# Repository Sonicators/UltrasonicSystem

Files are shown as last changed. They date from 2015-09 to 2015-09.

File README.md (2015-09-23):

A small ultrasonic system which can be used by hobbyists for:

* Mixing
* Cell disruption
* Levitation
* Cavitation experiments
* Ultrasonic chemistry
* ...and other tasks

The system consists of a transducer, a tuned aluminum horn, an ATX supply for power, an SMPS transformer from a second power supply, a PCB power driver, and mounting hardware.

Not counting the two ATX power supplies, a complete system can be made for around $60USD, more or less, depending on how good you are at scavenging.

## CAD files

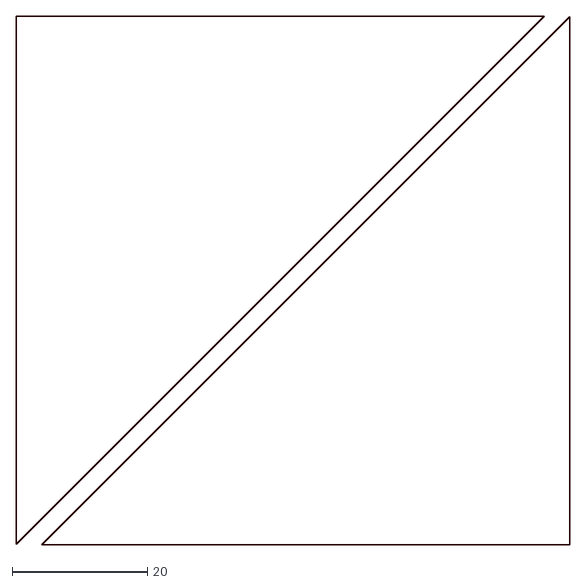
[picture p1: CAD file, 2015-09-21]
Hardware/45mm/CameraMount/BraceCorners.dxf
81.8 x 78.1

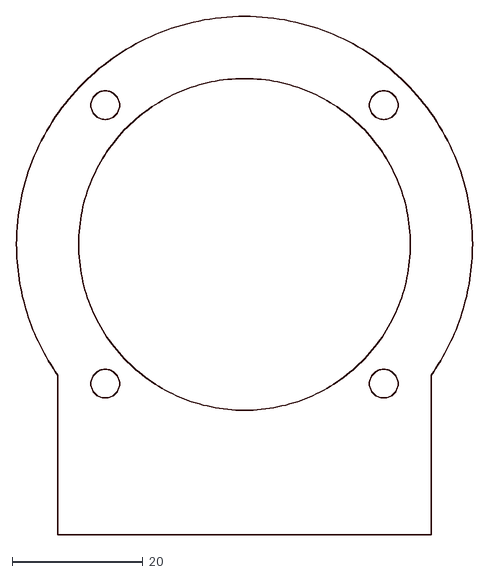
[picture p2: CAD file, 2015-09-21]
Hardware/45mm/Clamp/UpperClamp.dxf
69.8 x 79.4

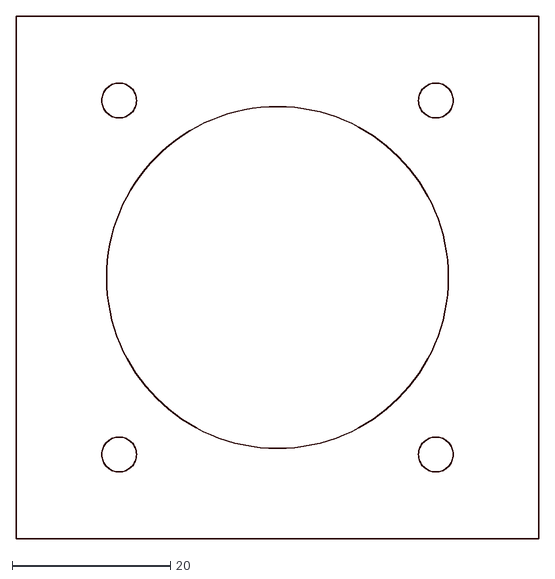
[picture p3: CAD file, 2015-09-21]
Hardware/45mm/DrillPressMount/Ring.dxf
66.0 x 66.0

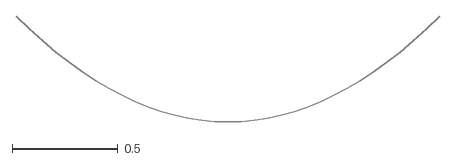
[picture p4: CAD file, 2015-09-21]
Hardware/45mm/ParabolicHorn/Anvil/Parabola Diameter 1.75 Depth .25.dxf
2.00 x 0.5

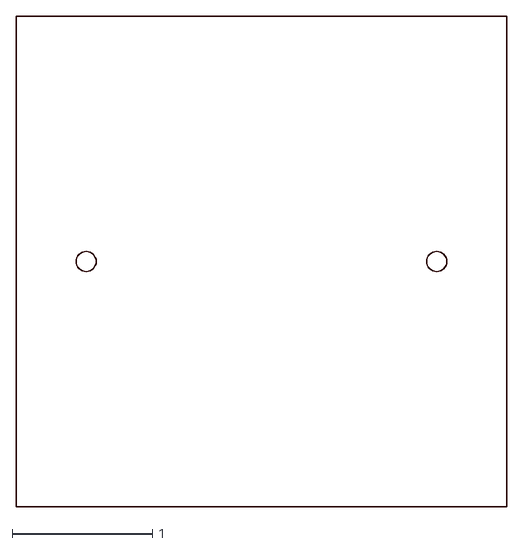
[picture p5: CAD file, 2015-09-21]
Hardware/45mm/ParabolicHorn/AnvilBase/AnvilBase.dxf
3.50 x 3.50

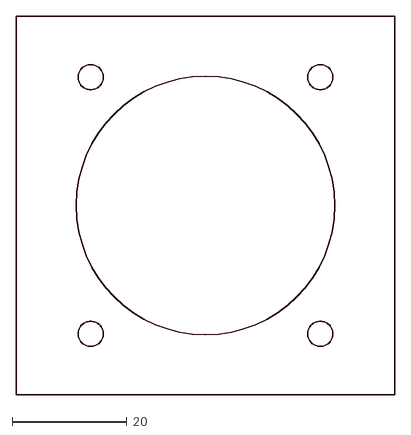
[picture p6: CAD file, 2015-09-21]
Hardware/45mm/ParabolicHorn/DrillPressMount/Ring.dxf
66.0 x 66.0

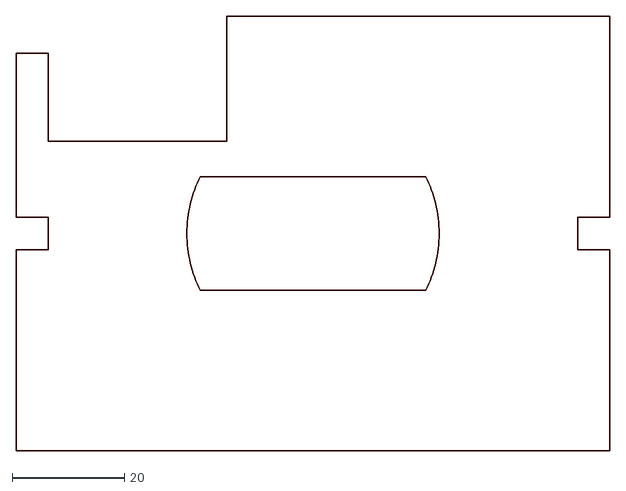
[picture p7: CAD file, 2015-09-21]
Hardware/45mm/ParabolicHorn/ReactionChamber/Top.dxf
105.6 x 77.3

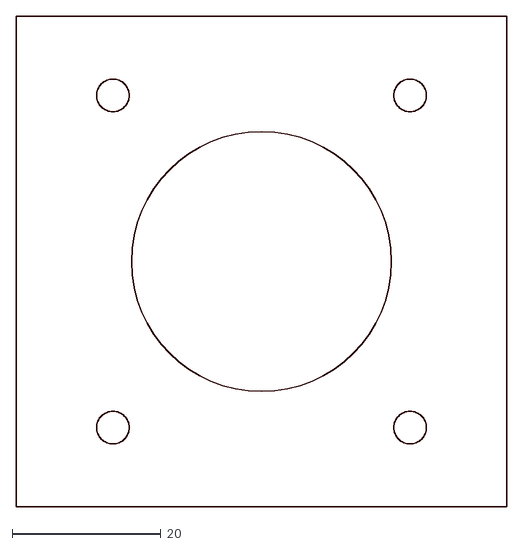
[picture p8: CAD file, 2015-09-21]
Hardware/45mm/StepHorn/DrillPressMount/LowerClamp.dxf
66.0 x 66.0

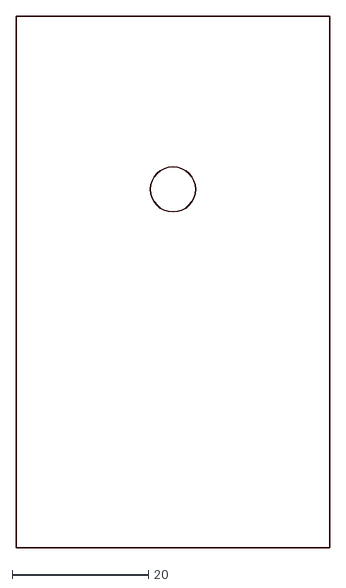
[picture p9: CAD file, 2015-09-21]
Hardware/67mm/CameraMount/CameraBase.dxf
46.0 x 78.0

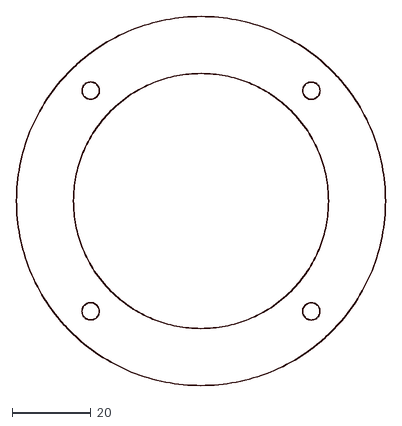
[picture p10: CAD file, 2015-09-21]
Hardware/67mm/Clamp/Ring.dxf
93.6 x 93.6

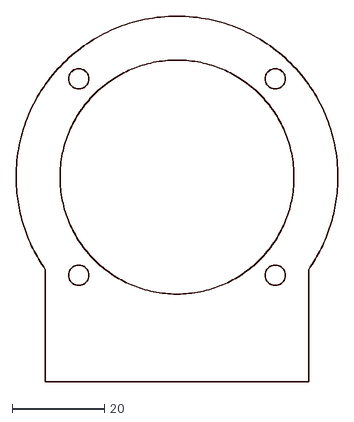
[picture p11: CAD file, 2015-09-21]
Hardware/45mm/CameraMount/UpperClamp.dxf
69.8 x 79.4

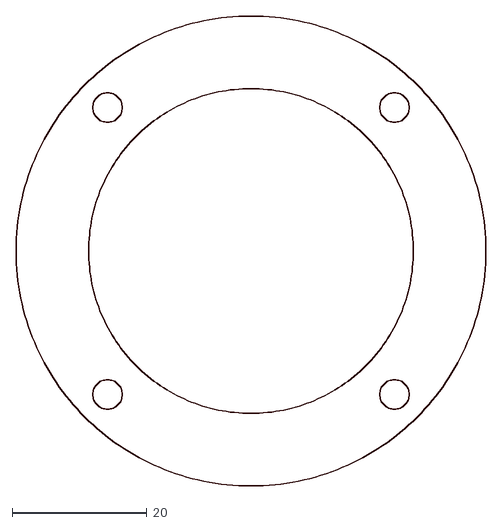
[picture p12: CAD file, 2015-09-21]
Hardware/45mm/Clamp/Ring.dxf
69.8 x 69.8

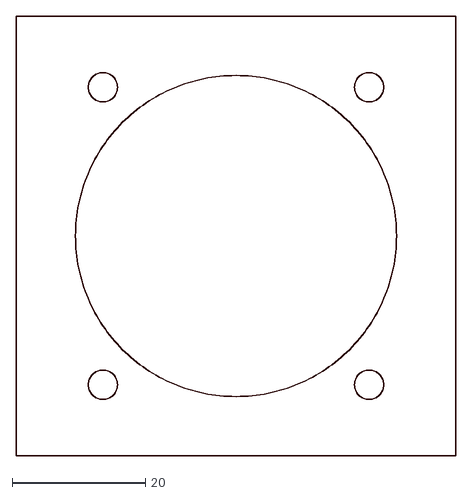
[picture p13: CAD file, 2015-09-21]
Hardware/45mm/DrillPressMount/LowerClamp.dxf
66.0 x 66.0

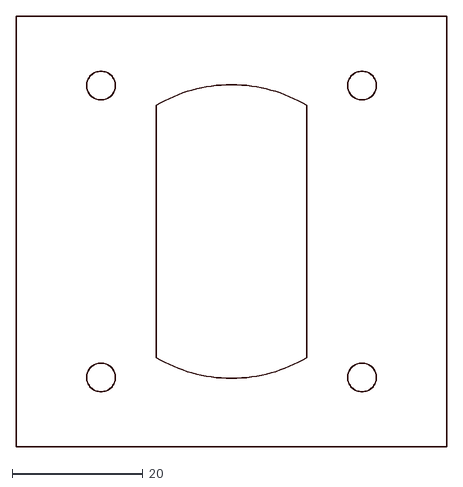
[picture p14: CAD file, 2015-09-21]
Hardware/45mm/ParabolicHorn/DrillPressMount/LowerClamp.dxf
66.0 x 66.0

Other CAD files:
Hardware/45mm/ParabolicHorn/ReactionChamber/Front.dxf
Hardware/45mm/StepHorn/DrillPressMount/UpperClamp.dxf
Hardware/45mm/CameraMount/CameraBase.dxf
Hardware/45mm/CameraMount/LowerClamp.dxf
Hardware/45mm/CameraMount/Ring.dxf
Hardware/45mm/Clamp/LowerClamp.dxf
Hardware/45mm/DrillPressMount/UpperClamp.dxf
Hardware/45mm/ParabolicHorn/DrillPressMount/Gasket.dxf
Hardware/45mm/ParabolicHorn/DrillPressMount/UpperClamp.dxf
Hardware/45mm/ParabolicHorn/ReactionChamber/Back.dxf
Hardware/45mm/ParabolicHorn/ReactionChamber/Base.dxf
Hardware/45mm/ParabolicHorn/ReactionChamber/Gasket.dxf
Hardware/45mm/ParabolicHorn/ReactionChamber/HolderNut.dxf
Hardware/45mm/ParabolicHorn/ReactionChamber/Side.dxf
Hardware/45mm/ParabolicHorn/ReactionChamber/TopRoundGasket.dxf
Hardware/45mm/ParabolicHorn/ReactionChamber/TopRoundWide.dxf
Hardware/45mm/ParabolicHorn/ReactionChamber/TubeHolder.dxf
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

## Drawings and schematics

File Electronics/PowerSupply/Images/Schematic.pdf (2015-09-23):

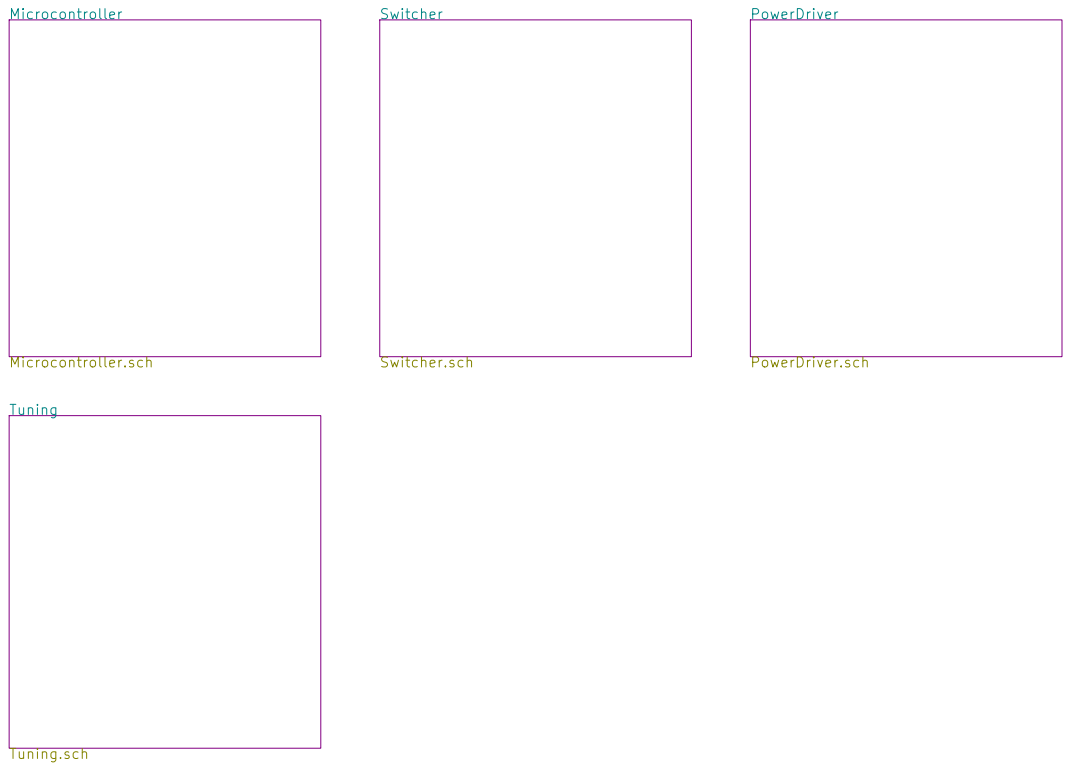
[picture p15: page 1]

Switcher.sch Microcontroller Microcontroller.sch Tuning

PowerDriver PowerDriver.sch Switcher

File: Schematic.sch Sheet: / Tool Chain Gang

Id: 1/5 Title: 120 Watt Ultrasonic Power SUpply

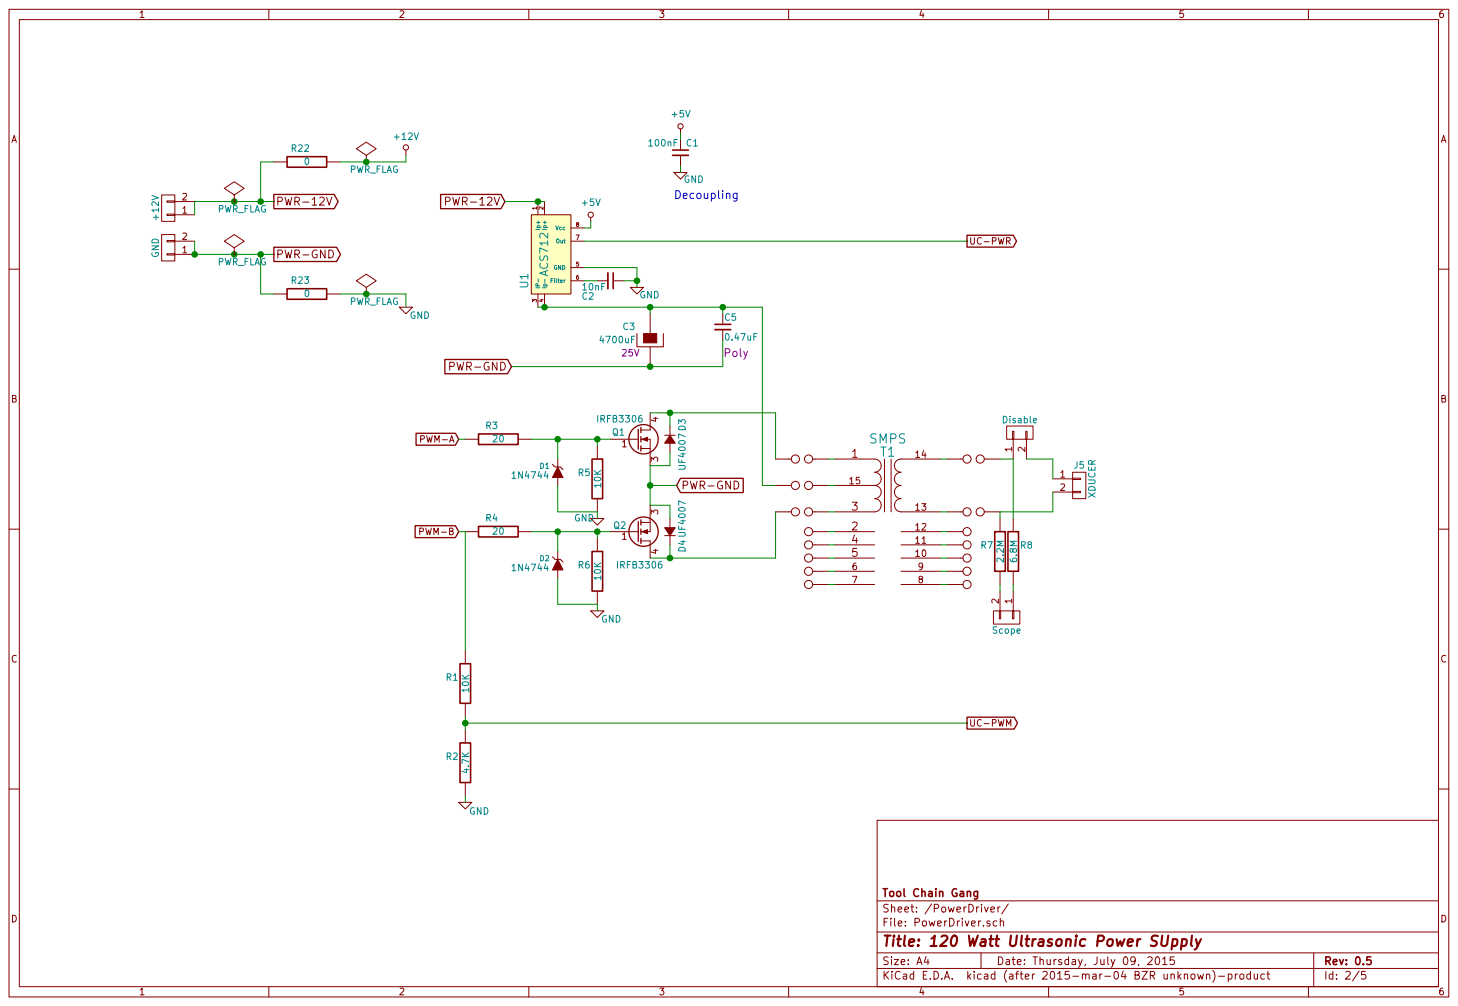
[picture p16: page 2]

2 IP- 3 Ip- 4 GND 5 Filter 6 Out 7 Vcc 8 U1ACS712 C2

File: PowerDriver.sch Sheet: /PowerDriver/ Tool Chain Gang

Id: 2/5 Title: 120 Watt Ultrasonic Power SUpply

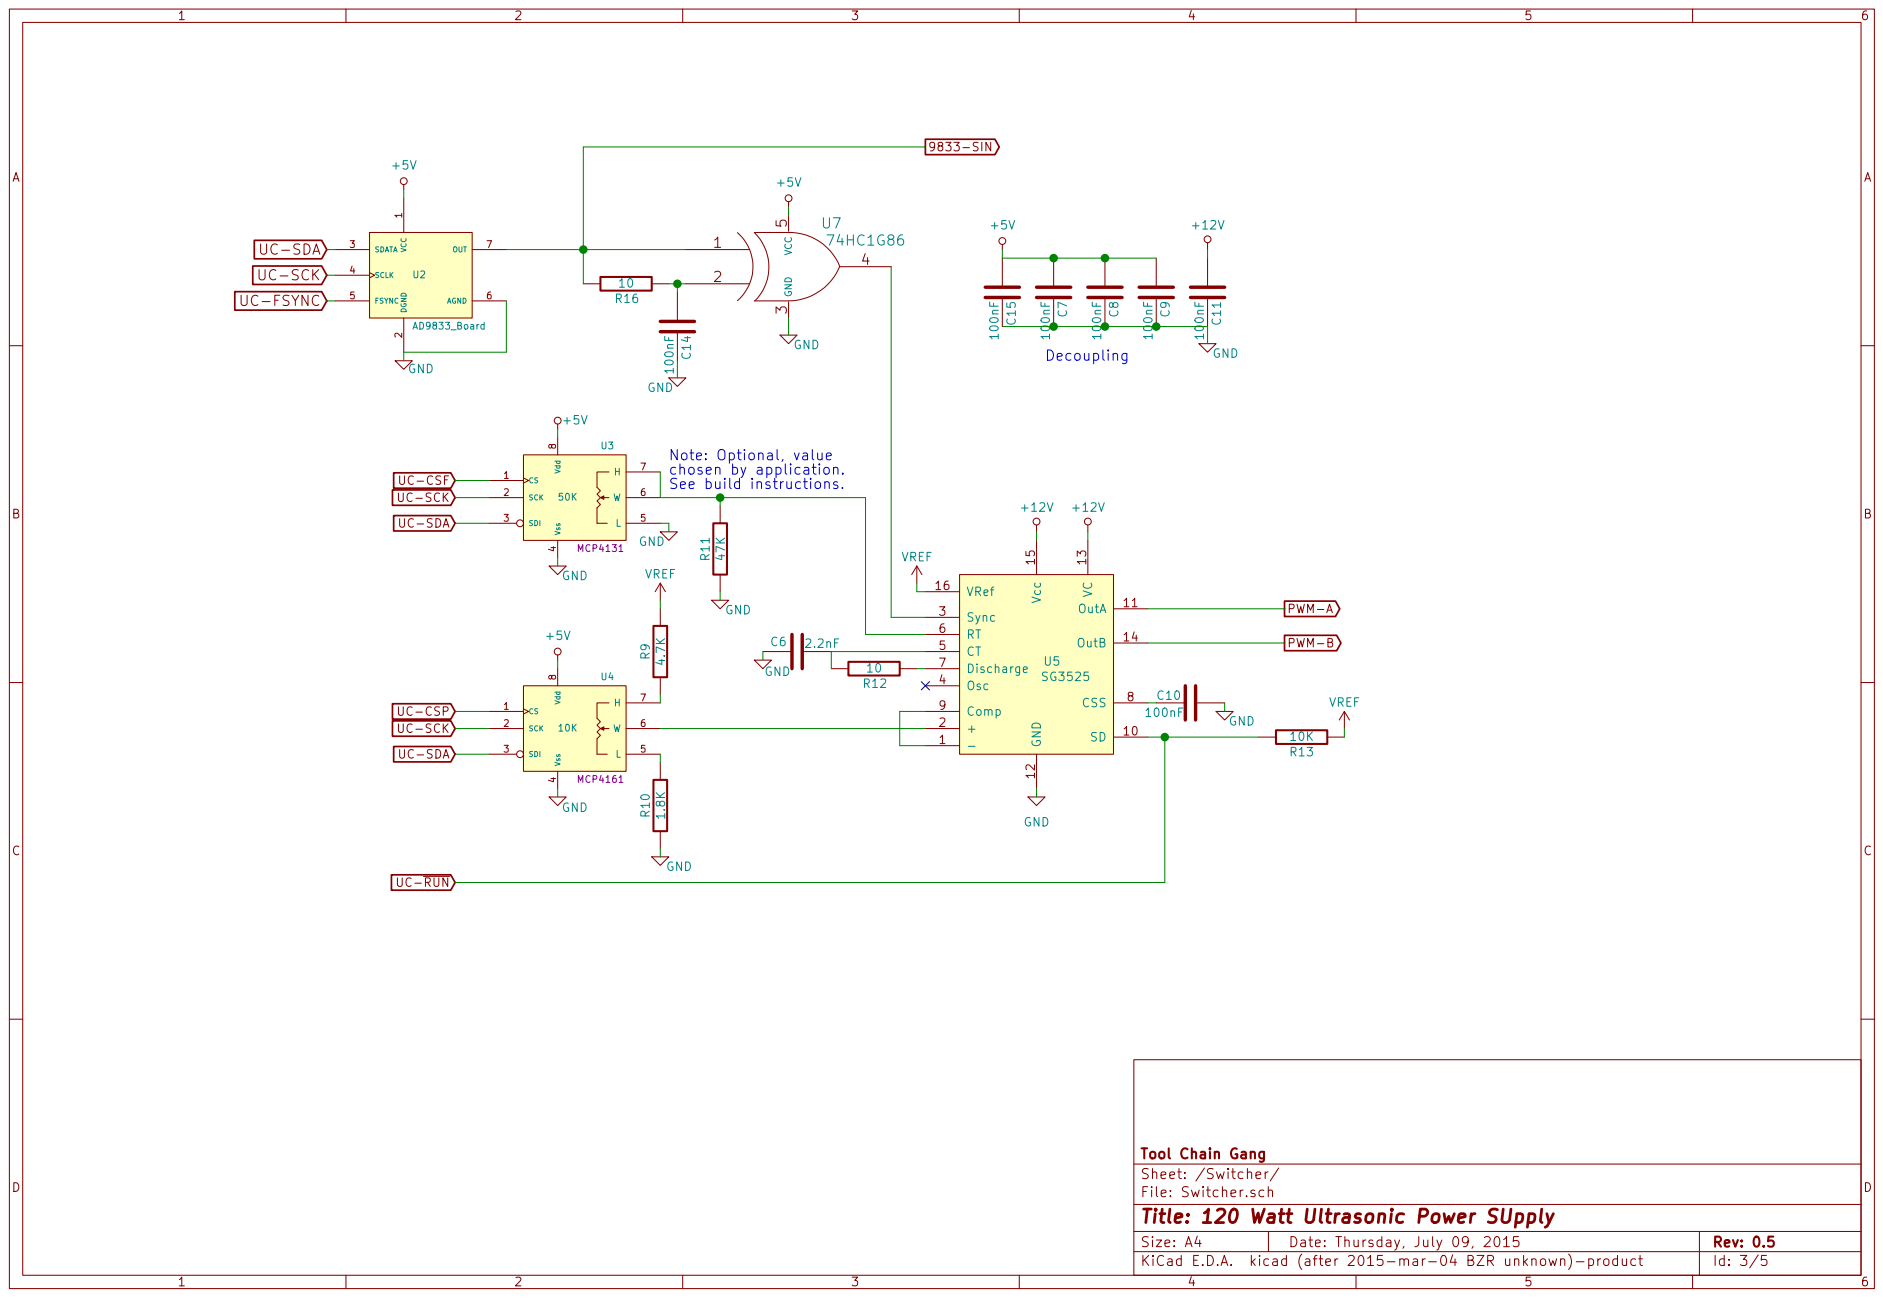
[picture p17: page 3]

See build instructions. VCC 1 DGND 2

+12V Decoupling R11 47K GND Note: Optional, value

File: Switcher.sch Sheet: /Switcher/ Tool Chain Gang R9 4.7K R10 1.8K

10K UC-CSP UC-SCK UC-SDA

Id: 3/5 Title: 120 Watt Ultrasonic Power SUpply

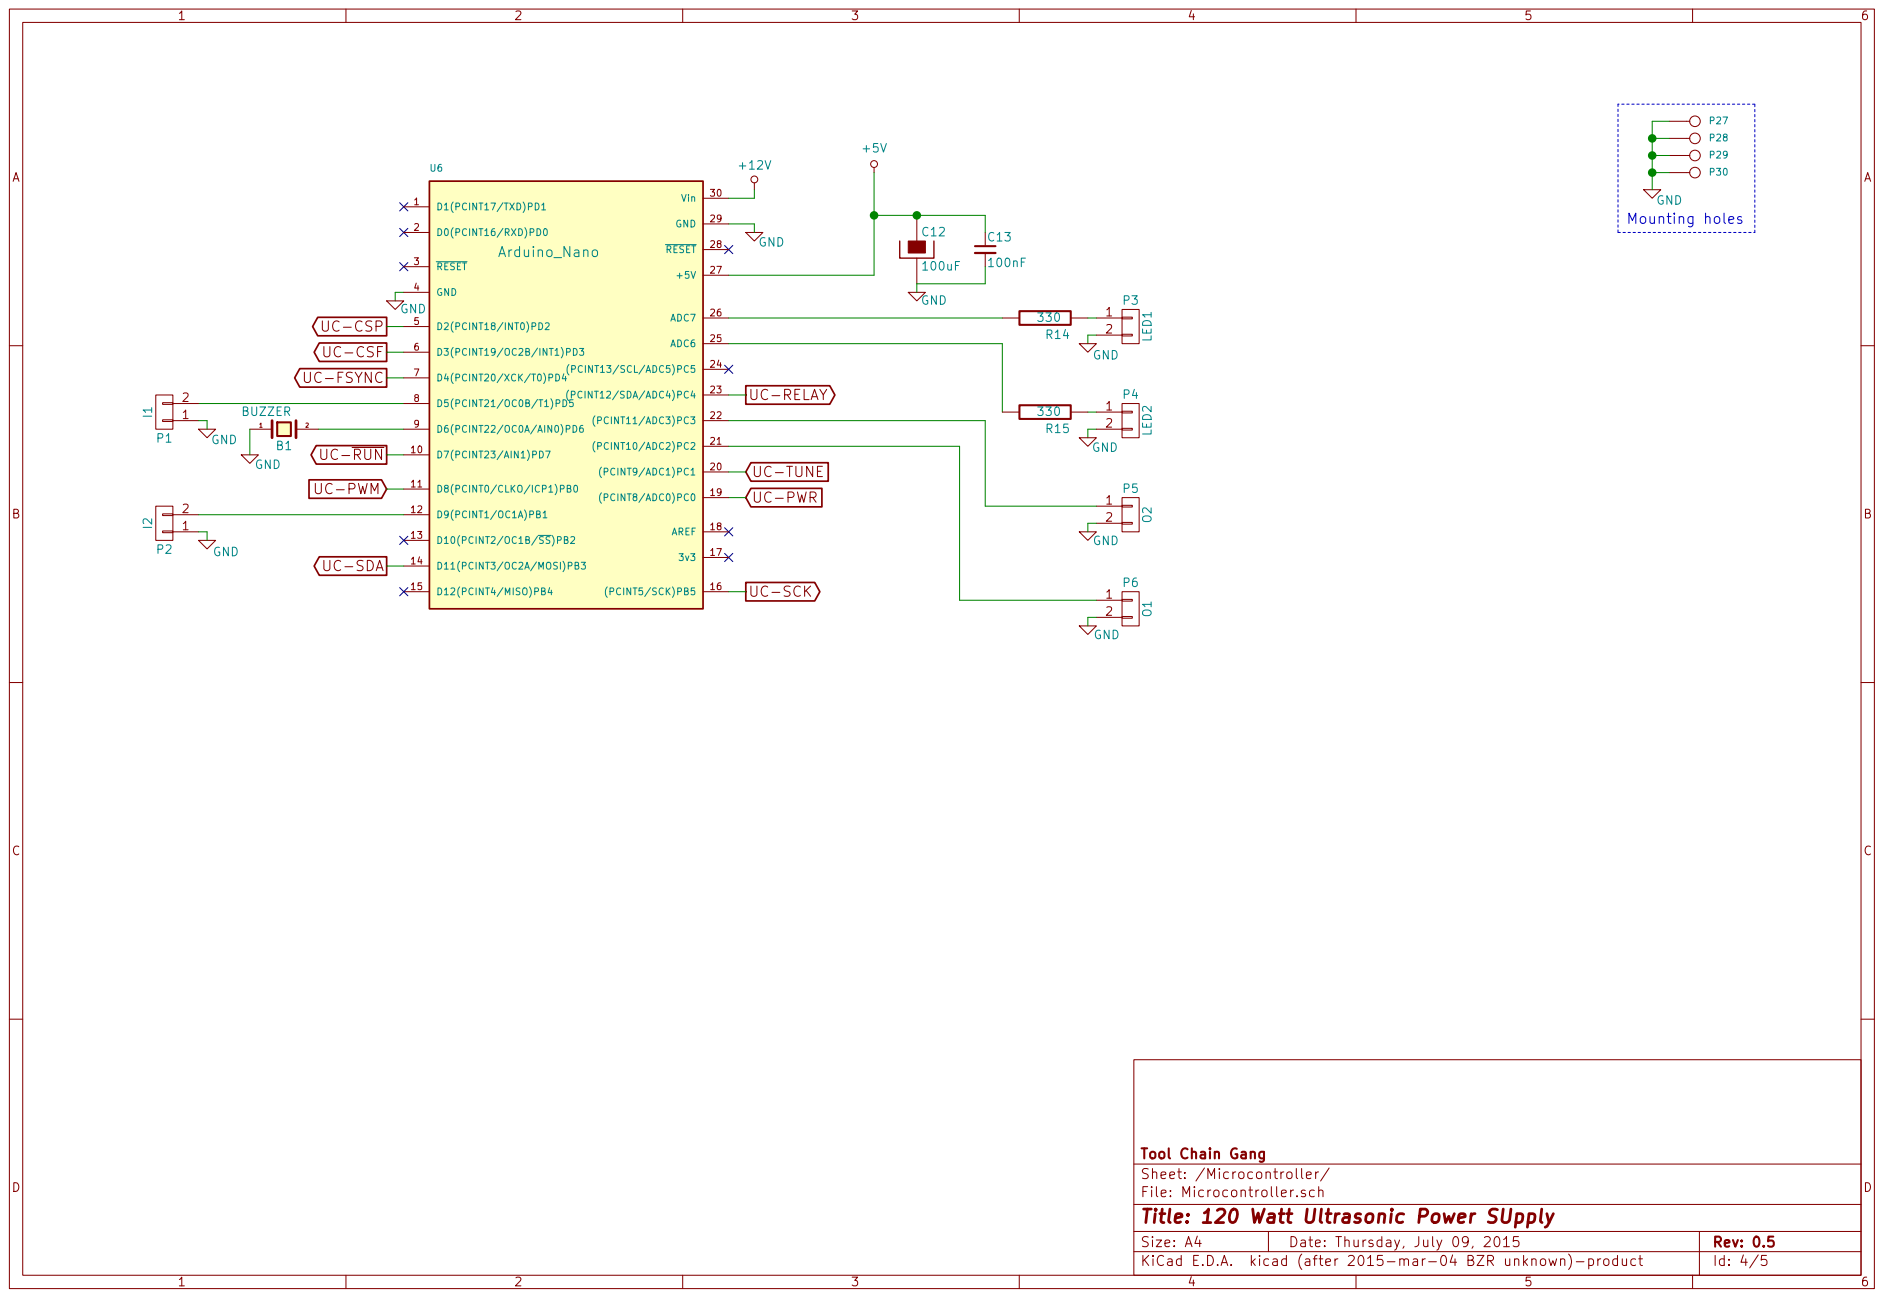
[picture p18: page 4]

File: Microcontroller.sch Sheet: /Microcontroller/ Tool Chain Gang

Id: 4/5 Title: 120 Watt Ultrasonic Power SUpply

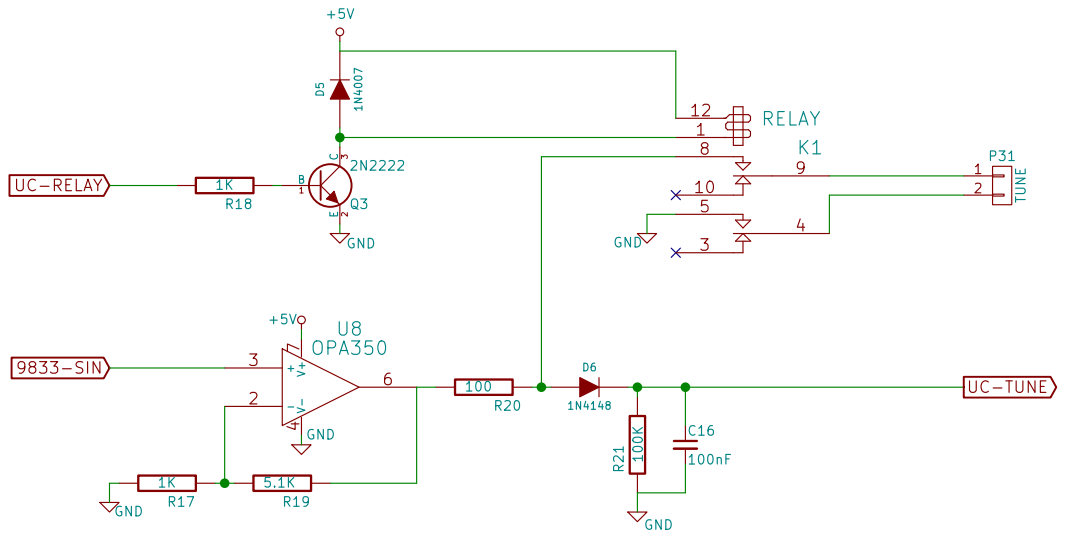
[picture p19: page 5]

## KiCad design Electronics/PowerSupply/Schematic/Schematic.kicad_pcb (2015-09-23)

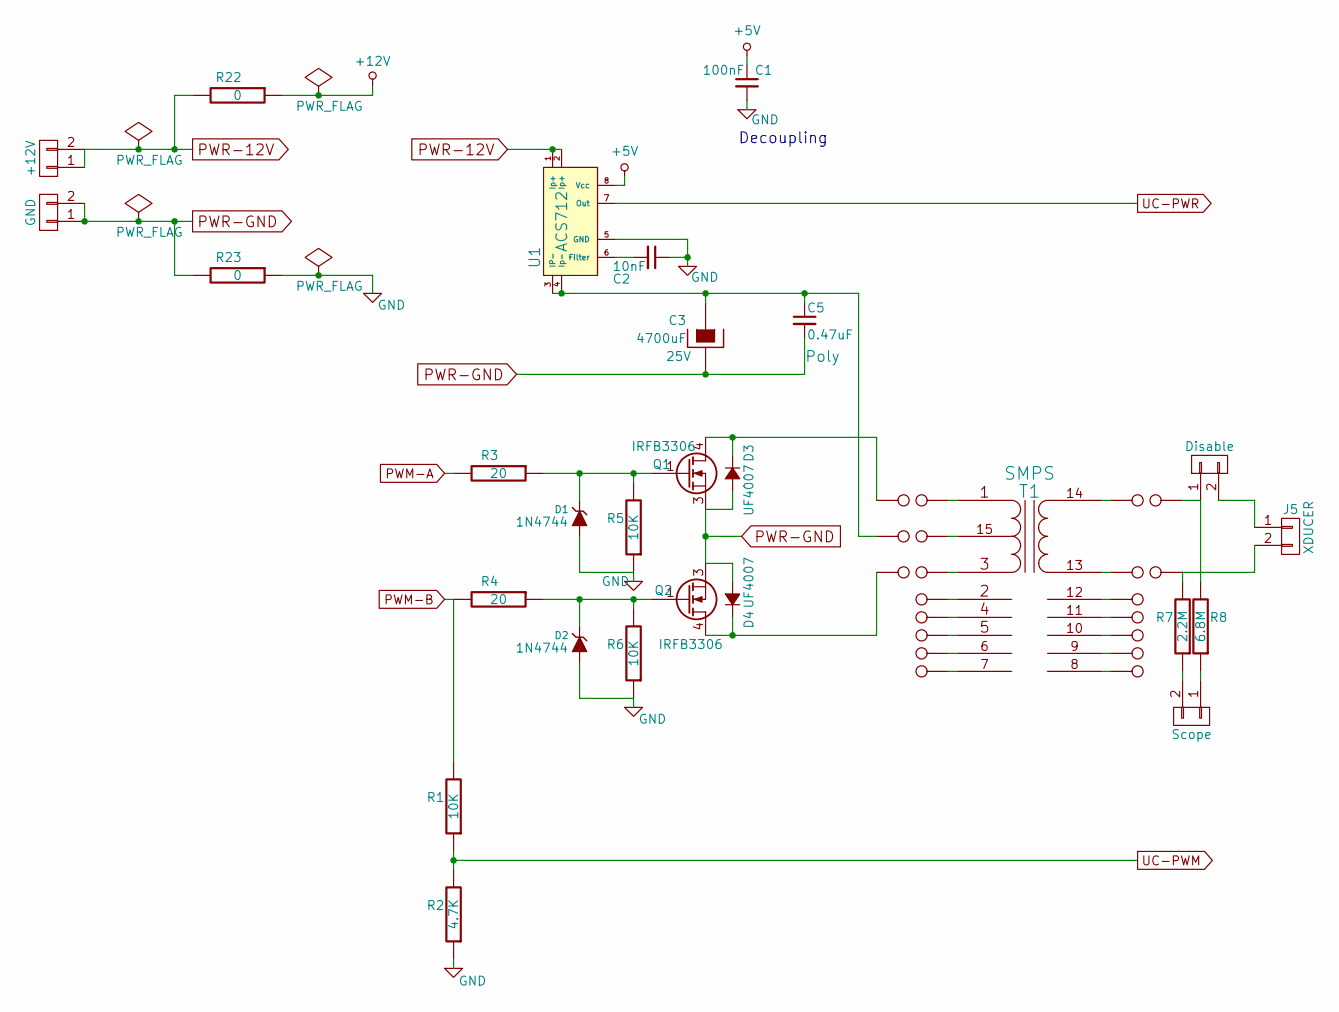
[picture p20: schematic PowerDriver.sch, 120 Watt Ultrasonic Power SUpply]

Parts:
C1: 100nF; C_0805_HandSoldering
C2: 10nF; C_0805_HandSoldering
C3: 4700uF; C_Radial_D18_L36_P7.5; Voltage 25V
C5: 0.47uF; C_Rect_L18_W9_H15_P15
D1, D2: 1N4744; Diode_DO-41_SOD81_Horizontal_RM10
D3, D4: UF4007; Diode_DO-41_SOD81_Horizontal_RM10
J1: +12V; AK300-2
J2: GND; AK300-2
J3: Scope; PINHEAD1-2
J4: Disable; AK300-2
J5: XDUCER; AK300-2
P7: SMPS-UT; 1pin
P8: SMPS-CT; 1pin
P9: SMPS-LT; 1pin
P10, P11, P12, P13, P14, P15, P16, P17, P18, P19, P20, P21, P22, P23, P24, P25, P26: CONN_1; 1pin
Q1, Q2: IRFB3306; TO-220_Neutral123_Horizontal_LargePads
R1, R5, R6: 10K; R_0805_HandSoldering
R2: 4.7K; R_0805_HandSoldering
R3, R4: 20; R_0805_HandSoldering
R7: 2.2M; R_0805_HandSoldering
R8: 6.8M; R_0805_HandSoldering
R22, R23: 0; TEST_POINT_2PADS
T1: SMPS; SMPS_Transformer
U1: ACS712; SOIC-8-N

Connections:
+5V: C1.1, U1.8 (Vcc); also elsewhere on the board
+12V: R22.1; also elsewhere on the board
GND: C1.2, C2.1, D1.1 (A), D2.1 (A), R2.1, R5.1, R6.1, R23.1, U1.5 (GND); also elsewhere on the board
unnamed: C2.2, U1.6 (Filter)
unnamed: C3.1, C5.1, P8.1, U1.3 (IP-), U1.4 (Ip-)
unnamed: D1.2 (K), Q1.1 (G), R3.1, R5.2
unnamed: D2.2 (K), Q2.1 (G), R4.1, R6.2
unnamed: D3.2 (C), P7.1, Q1.4 (D)
unnamed: D4.2 (C), P9.1, Q2.4 (D)
unnamed: J3.1, R8.1
unnamed: J3.2, R7.1
unnamed: J4.1, P25.1, R8.2
unnamed: J4.2, J5.1
unnamed: J5.2, P26.1, R7.2
unnamed: P10.1, T1.1 (PR1)
unnamed: P11.1, T1.15 (TAIL)
unnamed: P12.1, T1.3 (PR2)
unnamed: P13.1, T1.2 (PM)
unnamed: P14.1, T1.4 (S1)
unnamed: P15.1, T1.5 (S2)
unnamed: P16.1, T1.6
unnamed: P17.1, T1.7
unnamed: P18.1, T1.14
unnamed: P19.1, T1.13
unnamed: P20.1, T1.12
unnamed: P21.1, T1.11
unnamed: P22.1, T1.10
unnamed: P23.1, T1.9
unnamed: P24.1, T1.8
PWM-A: R3.2; also elsewhere on the board
PWM-B: R1.2, R4.2; also elsewhere on the board
PWR-12V: J1.1, J1.2, R22.2, U1.1 (Ip+), U1.2 (Ip+)
PWR-GND: C3.2, C5.2, D3.1 (A), D4.1 (A), J2.1, J2.2, Q1.3 (S), Q2.3 (S), R23.2
UC-PWM: R1.1, R2.2; also elsewhere on the board
UC-PWR: U1.7 (Out); also elsewhere on the board

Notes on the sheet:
Decoupling

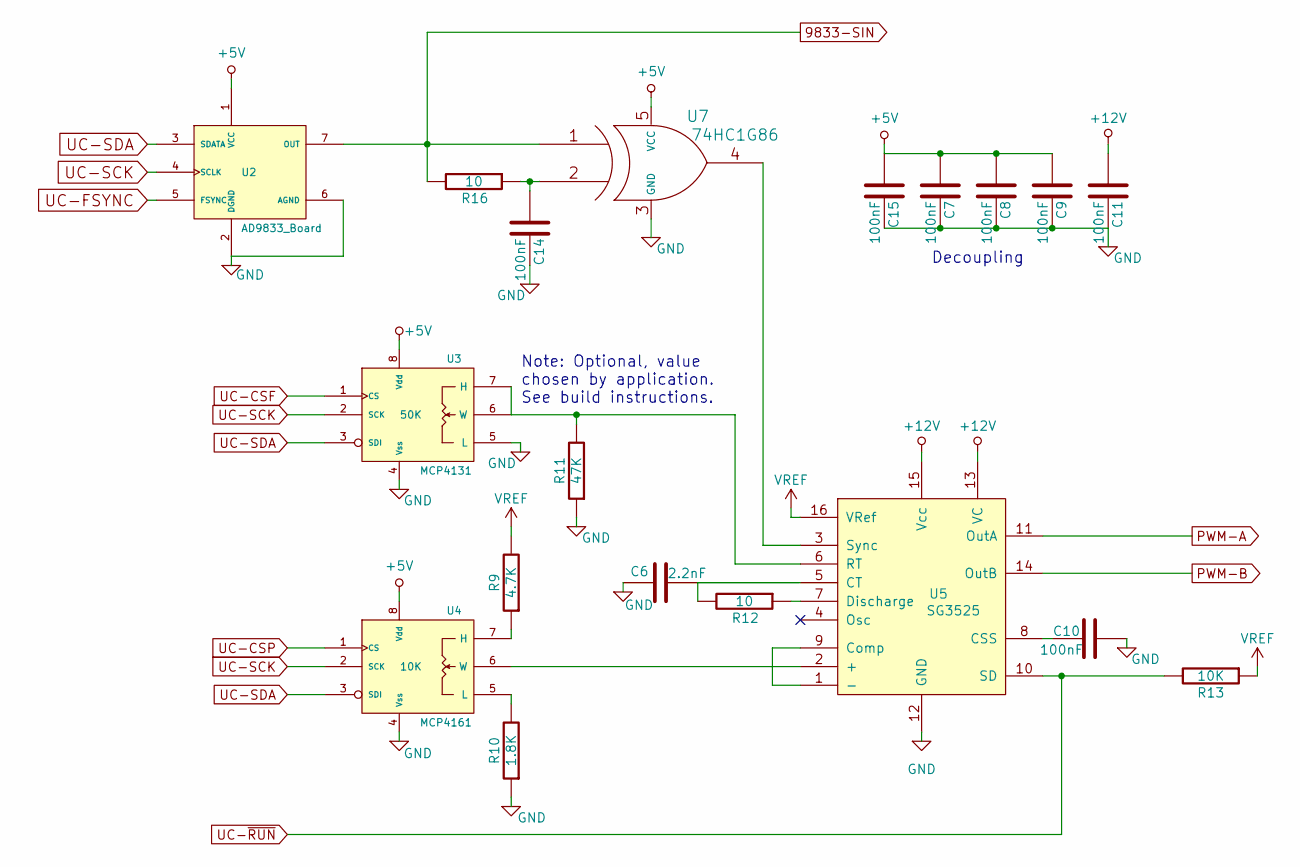
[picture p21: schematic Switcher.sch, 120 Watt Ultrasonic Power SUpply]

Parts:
C6: 2.2nF; C_0603_HandSoldering
C7, C8, C9, C10, C11, C14, C15: 100nF; C_0805_HandSoldering
R9: 4.7K; R_0805_HandSoldering
R10: 1.8K; R_0805_HandSoldering
R11: 47K; PINHEAD1-2
R12, R16: 10; R_0805_HandSoldering
R13: 10K; R_0805_HandSoldering
U2: AD9833_Board
U3: 50K; DIP-8_W7.62mm_LongPads
U4: 10K; DIP-8_W7.62mm_LongPads
U5: SG3525; DIP-16_W7.62mm_LongPads
U7: 74HC1G86; SOT-23-5

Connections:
9833-SIN: R16.2, U2.7 (OUT), U7.1; also elsewhere on the board
+5V: C7.2, C8.2, C9.2, C15.2, U2.1 (VCC), U3.8 (Vdd), U4.8 (Vdd), U7.5 (VCC); also elsewhere on the board
+12V: C11.2, U5.13 (VC), U5.15 (Vcc); also elsewhere on the board
GND: C6.1, C7.1, C8.1, C9.1, C10.1, C11.1, C14.1, C15.1, R10.1, R11.1, U2.2 (DGND), U2.6 (AGND), U3.4 (Vss), U3.5 (L), U4.4 (Vss), U5.12 (GND), U7.3 (GND); also elsewhere on the board
unnamed: C6.2, R12.2, U5.5 (CT)
unnamed: C10.2, U5.8 (CSS)
unnamed: C14.2, R16.1, U7.2
unnamed: R9.1, U4.7 (H)
unnamed: R10.2, U4.5 (L)
unnamed: R11.2, U3.6 (W), U3.7 (H), U5.6 (RT)
unnamed: R12.1, U5.7 (Discharge)
unnamed: U4.6 (W), U5.2 (+)
unnamed: U5.1 (-), U5.9 (Comp)
unnamed: U5.3 (Sync), U7.4
PWM-A: U5.11 (OutA); also elsewhere on the board
PWM-B: U5.14 (OutB); also elsewhere on the board
UC-CSF: U3.1 (CS); also elsewhere on the board
UC-CSP: U4.1 (CS); also elsewhere on the board
UC-FSYNC: U2.5 (FSYNC); also elsewhere on the board
UC-SCK: U2.4 (SCLK), U3.2 (SCK), U4.2 (SCK); also elsewhere on the board
UC-SDA: U2.3 (SDATA), U3.3 (SDI), U4.3 (SDI); also elsewhere on the board
UC-~RUN: R13.2, U5.10 (SD); also elsewhere on the board
VREF: R9.2, R13.1, U5.16 (VRef)

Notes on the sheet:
Decoupling
Note: Optional, value chosen by application. See build instructions.

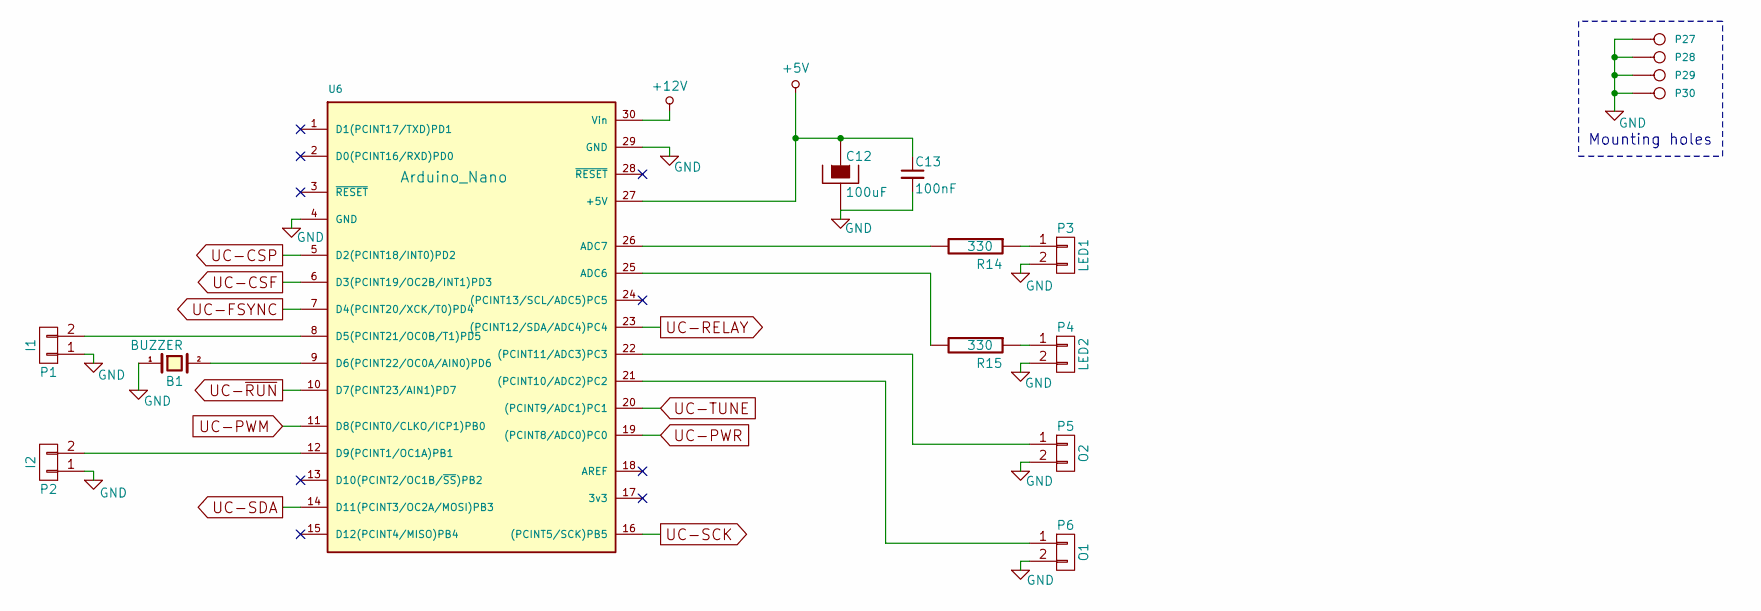
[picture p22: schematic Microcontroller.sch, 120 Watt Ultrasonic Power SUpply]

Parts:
B1: BUZZER; BUZ3-5
C12: 100uF; c_elec_8x6.7
C13: 100nF; C_0805_HandSoldering
P1: I1; PINHEAD1-2
P2: I2; PINHEAD1-2
P3: LED1; PINHEAD1-2
P4: LED2; PINHEAD1-2
P5: O2; PINHEAD1-2
P6: O1; PINHEAD1-2
P27, P28, P29, P30: CONN_1; 1pin
R14, R15: 330; R_0805_HandSoldering
U6: Arduino_Nano; DIP-30_W15.24mm_LongPads

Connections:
+5V: C12.1, C13.1, U6.27 (+5V); also elsewhere on the board
+12V: U6.30 (Vin); also elsewhere on the board
GND: B1.1, C12.2, C13.2, P1.1, P2.1, P3.2, P4.2, P5.2, P6.2, P27.1, P28.1, P29.1, P30.1, U6.4 (GND), U6.29 (GND); also elsewhere on the board
unnamed: B1.2, U6.9 (D6(PCINT22/OC0A/AIN0)PD6)
unnamed: P1.2, U6.8 (D5(PCINT21/OC0B/T1)PD5)
unnamed: P2.2, U6.12 (D9(PCINT1/OC1A)PB1)
unnamed: P3.1, R14.1
unnamed: P4.1, R15.1
unnamed: P5.1, U6.22 ((PCINT11/ADC3)PC3)
unnamed: P6.1, U6.21 ((PCINT10/ADC2)PC2)
unnamed: R14.2, U6.26 (ADC7)
unnamed: R15.2, U6.25 (ADC6)
UC-CSF: U6.6 (D3(PCINT19/OC2B/INT1)PD3); also elsewhere on the board
UC-CSP: U6.5 (D2(PCINT18/INT0)PD2); also elsewhere on the board
UC-FSYNC: U6.7 (D4(PCINT20/XCK/T0)PD4); also elsewhere on the board
UC-PWM: U6.11 (D8(PCINT0/CLKO/ICP1)PB0); also elsewhere on the board
UC-PWR: U6.19 ((PCINT8/ADC0)PC0); also elsewhere on the board
UC-RELAY: U6.23 ((PCINT12/SDA/ADC4)PC4); also elsewhere on the board
UC-SCK: U6.16 ((PCINT5/SCK)PB5); also elsewhere on the board
UC-SDA: U6.14 (D11(PCINT3/OC2A/MOSI)PB3); also elsewhere on the board
UC-TUNE: U6.20 ((PCINT9/ADC1)PC1); also elsewhere on the board
UC-~RUN: U6.10 (D7(PCINT23/AIN1)PD7); also elsewhere on the board

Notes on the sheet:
Mounting holes

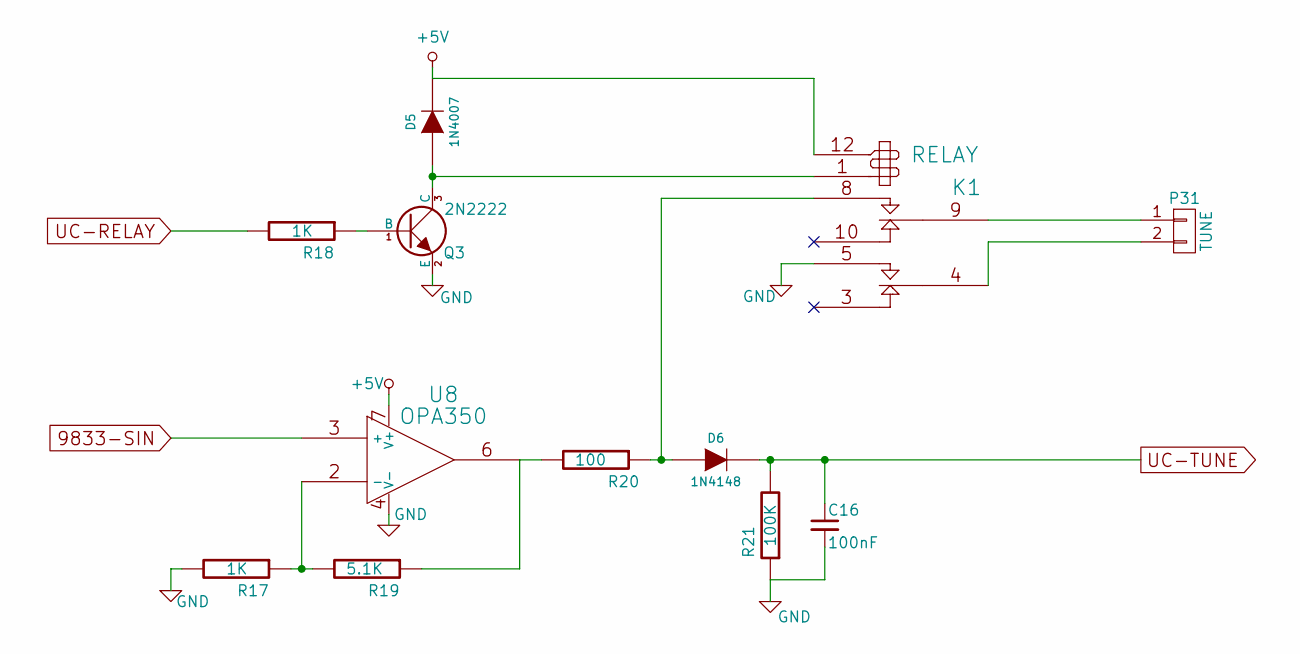
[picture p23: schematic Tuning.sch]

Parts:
C16: 100nF; C_0805_HandSoldering
D5: 1N4007; Diode_DO-41_SOD81_Horizontal_RM10
D6: 1N4148; Diode_DO-41_SOD81_Horizontal_RM10
K1: RELAY; Relay_DPDT_IM0(3,6,7)NS
P31: TUNE; PINHEAD1-2
Q3: 2N2222; SOT-23_Handsoldering
R17, R18: 1K; R_0805_HandSoldering
R19: 5.1K; R_0805_HandSoldering
R20: 100; R_0805_HandSoldering
R21: 100K; R_0805_HandSoldering
U8: OPA350; SOIC-8-N

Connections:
9833-SIN: U8.3 (+); also elsewhere on the board
+5V: D5.2 (K), K1.12, U8.7 (V+); also elsewhere on the board
GND: C16.2, K1.5 (T2), Q3.2 (E), R17.2, R21.1, U8.4 (V-); also elsewhere on the board
unnamed: D5.1 (A), K1.1, Q3.3 (C)
unnamed: D6.1 (A), K1.8 (T1), R20.1
unnamed: K1.4 (C2), P31.2
unnamed: K1.9 (C1), P31.1
unnamed: Q3.1 (B), R18.1
unnamed: R17.1, R19.2, U8.2 (-)
unnamed: R19.1, R20.2, U8.6
UC-RELAY: R18.2; also elsewhere on the board
UC-TUNE: C16.1, D6.2 (K), R21.2; also elsewhere on the board

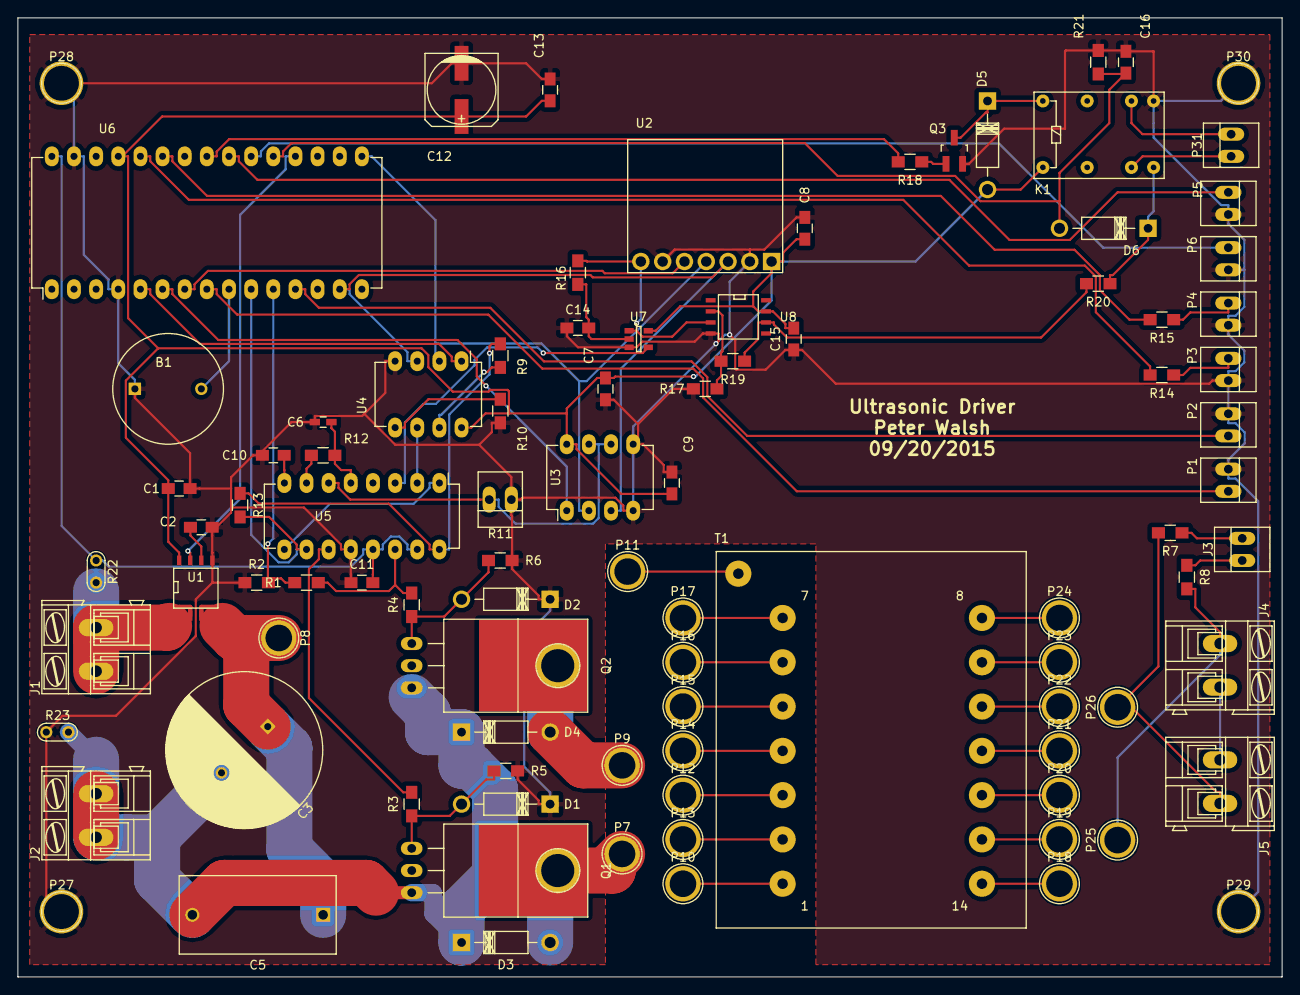
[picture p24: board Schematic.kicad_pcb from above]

Board: 2 copper layers, 145.0 x 110.0 mm, 94 parts (0 on the bottom side), 71 nets.

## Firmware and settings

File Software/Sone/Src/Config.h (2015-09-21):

//////////////////////////////////////////////////////////////////////////////////////////
//////////////////////////////////////////////////////////////////////////////////////////
//
//      Copyright (C) 2015 Peter Walsh, Milford, NH 03055
//      All Rights Reserved under the MIT license as outlined below.
//
//  FILE
//      Config.h
//
//  SYNOPSIS
//
//      Collect all the PORT/BIT assignments in one file, for ease in managing
//
//  DESCRIPTION
//
//      A system with one or two hardware interface is relatively straightforward to
//        manage, When you have a lot of them, it makes more sense to put everything
//        in one file, so that conflicts are readily apparent.
//
//////////////////////////////////////////////////////////////////////////////////////////
//
//  MIT LICENSE
//
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
//////////////////////////////////////////////////////////////////////////////////////////
//////////////////////////////////////////////////////////////////////////////////////////

#ifndef CONFIG_H
#define CONFIG_H

//////////////////////////////////////////////////////////////////////////////////////////
//////////////////////////////////////////////////////////////////////////////////////////
//
// EEPROM memory layout
//
#define EEPROM_CURR_VERSION 7


//////////////////////////////////////////////////////////////////////////////////////////
//////////////////////////////////////////////////////////////////////////////////////////
//
//  PORT USAGE TABLE
//
//      PORTB.5     SPI     SCK
//      PORTB.4     SPI     MISO
//      PORTB.3     SPI     MOSI
//      PORTB.2     SPI     SS
//      PORTB.1     INPUTS  I2
//      PORTB.0     PWM     ICP
//
//      PORTC.7     LEDs    LED1
//      PORTC.6     LEDs    LED2
//      PORTC.5
//      PORTC.4     TUNING  Tuning relay
//      PORTC.3     OUTPUTS O2
//      PORTC.2     OUTPUTS O1
//      PORTC.1     XDUCER  Tuning  sense (AtoD)
//      PORTC.0     ACS712  Current sense (AtoD)
//
//      PORTD.7     SG3525  Chip select
//      PORTD.6     BUZ     Buzzer
//      PORTD.5     INPUTS  I1
//      PORTD.4     AD9833  FSYNC (Chip select)
//      PORTD.3     FreqPot Chip Select
//      PORTD.2     PWMPot  Chip select
//      PORTD.1     UART    TxD
//      PORTD.0     UART    RxD
//
// NOTE: SS must not be used, since a high value will force the SPI out of master mode.
//


//////////////////////////////////////////////////////////////////////////////////////////
//////////////////////////////////////////////////////////////////////////////////////////
//////////////////////////////////////////////////////////////////////////////////////////
//////////////////////////////////////////////////////////////////////////////////////////
//
// ACS712 Hall-effect current monitor
//
#define ACS712_CHANNEL      0           // PortC.0

//////////////////////////////////////////////////////////////////////////////////////////
//////////////////////////////////////////////////////////////////////////////////////////
//
// Transducer tuning input
//
#define TUNING_CHANNEL      1           // PortC.1

//////////////////////////////////////////////////////////////////////////////////////////
//////////////////////////////////////////////////////////////////////////////////////////
//
// The ports and bits for outputs
//
#define OUTPUT1_PORT        C           // PortC
#define OUTPUT1_BIT         2           // Pin 2

#define OUTPUT2_PORT        C           // PortC
#define OUTPUT2_BIT         3           // Pin 3

//////////////////////////////////////////////////////////////////////////////////////////
//////////////////////////////////////////////////////////////////////////////////////////
//
// Tuning relay PortC
//
#define TUNE_RELAY_PORT     C           // PortC
#define TUNE_RELAY_BIT      4           // Pin 4

//////////////////////////////////////////////////////////////////////////////////////////
//////////////////////////////////////////////////////////////////////////////////////////
//
// Unused bits in PortC
//
#define UNUSEDC2_PORT       C           // PortC
#define UNUSEDC2_BIT        5           // Pin 5

//////////////////////////////////////////////////////////////////////////////////////////
//////////////////////////////////////////////////////////////////////////////////////////
//
// The ports and bits for LEDs
//
#define LED2_PORT           C           // PortC
#define LED2_BIT            6           // Pin 6

#define LED1_PORT           C           // PortC
#define LED1_BIT            7           // Pin 7
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

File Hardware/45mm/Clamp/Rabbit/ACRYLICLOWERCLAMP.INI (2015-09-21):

[CreateTechnicsCodeMgr]
PrjHasModifyCFG=1
[Technics_Laser_Data]
ModifyTechCFG=0
LayersNumber=2
LayerColor_0=3421236
LayerColor_1=16711680
ExportRows=1
ExportColumns=1
ExportRowSpace=0.00000
ExportColumnSpace=0.00000
ExportRowCW=0.00000
ExportColumnCW=0.00000
LogicOrgPositionX=565.07000
LogicOrgPositionY=410.31000
LogicOrgPositionZ=-9999999.00000
AtOnceExport=0
IsTwoLaserWorking=0
TableZeroPositionX=0.00000
TableZeroPositionY=0.00000
OutputTimes=1
DelayTime=0
FeedLength=0.00000
FeedSpeed=3.50000
FeedDelayTime=0
MinX=565.07427
MaxX=634.92573
MinY=410.31172
MaxY=489.68710
ChangeSerialNo=0
ArrayMinX=565.07427
ArrayMaxX=634.92573
ArrayMinY=410.31172
ArrayMaxY=489.68710
ClipBoxPower=40.00000
ClipBoxPower2=40.00000
ClipBoxOffsetLen=2.00000
ClipBoxSpeed=25.00000
AlignMachineZPos=0.00000
RouteLength=0.00000
RoutePointNumber=0
OffsetLaserPower=0.00000
OffsetWorkSpeedPer=1.00000
ZHeightForLaserFocus=0.00000
OneWorkNeedTimes=0
TotalWorkTimes=0
[CoordSystem_0]
LogicOrgPosition1=565.07000
LogicOrgPosition2=410.31000
LogicOrgPosition3=-9999999.00000
SPLITBLOCK_NUMBER=2
SPLITBLOCK_NUMBER_0=0.00000
SPLITBLOCK_NUMBER_1=100000.00000
[TechnicsLayers_3421236]
TechnicsMode=TECHNICS_LASERCUT
LaserCutConnerPower=70.00000
LaserCutWorkPower=80.00000
LaserCutConnerPower2=10.00000
LaserCutWorkPower2=80.00000
LaserCutFrequency=25000
LaserCutOptimizePathType=1
LaserCutInnerToOuter=1
LaserCutInnerToOuter2=0
LaserCutDownToUpper=0
LaserCutBlockHeight=200.00000
LaserCutAutoSetPathDir=1
LaserCutCicleMinSegNumber=36
LaserCutDisperseLength=0.10000
LaserCutCloseGapLength=0.03000
LaserCutOverlapLength=0.00000
LaserCutAdjustForClose=0
LaserCutQXEnterLength=0.00000
LaserCutDelayMoveTime=0.00000
LaserCutOpenGZDelayTime=0.00000
LaserCutOpenLaserDelayTime=0.00000
LaserCutCloseLaserDelayTime=0.00000
LaserCutDelayTimeAfterCloseLaser=0.00000
LaserCutOneAxisBackLashLength=0.00000
LaserCutTwoAxisBackLashLength=0.00000
LaserCutBackLashAddSpaceLength=8.00000
LaserCutBlowGasType=2
LaserCutAheadBlowGasTimes=0.01000
LaserCutNoCloseGasTimes=0.01000
LaserCutSpeed=10.00000
LaserCutGWAcc=200.00000
LaserCutGWTime=0.01000
LaserCutTrackSize=100
LaserCutLineLength=0.00000
SpaceCutLineLength=0.00000
bSpaceLineFirst=0
LaserCutAdjustMove=0
LaserCutAdjustMoveDelay=0.00000
LaserCutUpLen=0.00000
LaserCutCircleSpeedNum=6
LaserCutCircleSpeed0_MinR=0.00000
LaserCutCircleSpeed0_MaxR=0.55000
LaserCutCircleSpeed0_Speed=10.00000
LaserCutCircleSpeed1_MinR=0.55000
LaserCutCircleSpeed1_MaxR=1.05000
LaserCutCircleSpeed1_Speed=15.00000
LaserCutCircleSpeed2_MinR=1.05000
LaserCutCircleSpeed2_MaxR=1.55000
LaserCutCircleSpeed2_Speed=25.00000
LaserCutCircleSpeed3_MinR=1.55000
LaserCutCircleSpeed3_MaxR=2.05000
LaserCutCircleSpeed3_Speed=30.00000
LaserCutCircleSpeed4_MinR=2.05000
LaserCutCircleSpeed4_MaxR=3.05000
LaserCutCircleSpeed4_Speed=35.00000
LaserCutCircleSpeed5_MinR=3.05000
LaserCutCircleSpeed5_MaxR=4.05000
LaserCutCircleSpeed5_Speed=40.00000
GROUP_ROWS_0=1
GROUP_COLUMNS_0=1
GROUP_ROWSPACE_0=0.00000
GROUP_COLUMNSPACE_0=0.00000
GROUP_ROWCWSPACE_0=0.00000
GROUP_COLUMNCWSPACE_0=0.00000
GROUP_MINX_0=576.47442
GROUP_MAXX_0=623.52558
GROUP_MINY_0=431.23612
GROUP_MAXY_0=478.28727
[TechnicsLayers_16711680]
TechnicsMode=TECHNICS_LASERCUT
LaserCutConnerPower=70.00000
LaserCutWorkPower=80.00000
LaserCutConnerPower2=10.00000
LaserCutWorkPower2=80.00000
LaserCutFrequency=25000
LaserCutOptimizePathType=1
LaserCutInnerToOuter=1
LaserCutInnerToOuter2=0
LaserCutDownToUpper=0
LaserCutBlockHeight=200.00000
LaserCutAutoSetPathDir=1
LaserCutCicleMinSegNumber=36
LaserCutDisperseLength=0.10000
LaserCutCloseGapLength=0.03000
LaserCutOverlapLength=0.00000
LaserCutAdjustForClose=0
LaserCutQXEnterLength=0.00000
LaserCutDelayMoveTime=0.00000
LaserCutOpenGZDelayTime=0.00000
LaserCutOpenLaserDelayTime=0.00000
LaserCutCloseLaserDelayTime=0.00000
LaserCutDelayTimeAfterCloseLaser=0.00000
LaserCutOneAxisBackLashLength=0.00000
LaserCutTwoAxisBackLashLength=0.00000
LaserCutBackLashAddSpaceLength=8.00000
LaserCutBlowGasType=2
LaserCutAheadBlowGasTimes=0.01000
LaserCutNoCloseGasTimes=0.01000
LaserCutSpeed=10.00000
LaserCutGWAcc=200.00000
LaserCutGWTime=0.01000
LaserCutTrackSize=100
LaserCutLineLength=0.00000
SpaceCutLineLength=0.00000
bSpaceLineFirst=0
LaserCutAdjustMove=0
LaserCutAdjustMoveDelay=0.00000
LaserCutUpLen=0.00000
LaserCutCircleSpeedNum=6
LaserCutCircleSpeed0_MinR=0.00000
LaserCutCircleSpeed0_MaxR=0.55000
LaserCutCircleSpeed0_Speed=10.00000
LaserCutCircleSpeed1_MinR=0.55000
LaserCutCircleSpeed1_MaxR=1.05000
LaserCutCircleSpeed1_Speed=15.00000
LaserCutCircleSpeed2_MinR=1.05000
LaserCutCircleSpeed2_MaxR=1.55000
LaserCutCircleSpeed2_Speed=25.00000
LaserCutCircleSpeed3_MinR=1.55000
LaserCutCircleSpeed3_MaxR=2.05000
LaserCutCircleSpeed3_Speed=30.00000
LaserCutCircleSpeed4_MinR=2.05000
LaserCutCircleSpeed4_MaxR=3.05000
LaserCutCircleSpeed4_Speed=35.00000
LaserCutCircleSpeed5_MinR=3.05000
LaserCutCircleSpeed5_MaxR=4.05000
LaserCutCircleSpeed5_Speed=40.00000
GROUP_ROWS_0=1
GROUP_COLUMNS_0=1
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

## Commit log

2015-09-23 Completed Board layout and generated gerber files.
    [PowerDriver.sch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]
2015-09-23 Completed board layout, generated gerber files
